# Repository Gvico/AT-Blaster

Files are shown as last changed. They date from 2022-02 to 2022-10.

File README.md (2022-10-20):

# AT-Blaster

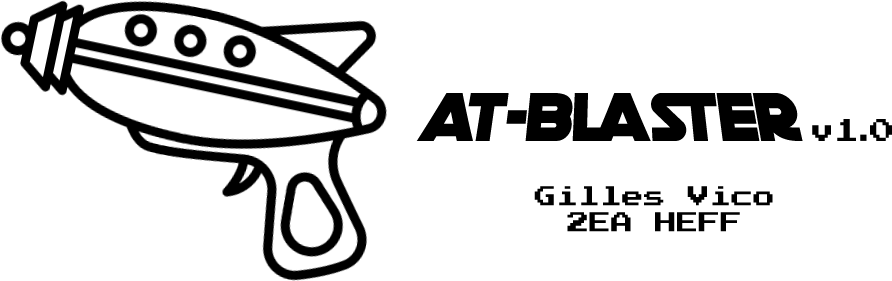
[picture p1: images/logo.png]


AT-Blaster is a BA2 project in Applied Electronics.
Its goal is to recreate a custom lasergame system.

## Project Specs

- **Microcontroller :** ATmega328P U-TH
- **IR Receiver :** VS1838B Module
- **RF Transceiver :** HC-12 Module
- **Display :** 16x2 characters LCD
- **Power :** 9V battery

- **PCB Dimensions :** 50x176mm
- **Case :** Designed on Fusion 360 and 3D printed
- **Components price (as of May 2021, excluding PCB and case) :** 43,51 €

## Features

### SW 1.0 (May 25th 2021)

#### - HW Blaster :

Blaster HW 1.0 support (Semi-automatic pistol)

#### - Free For All mode :

Unlimited lives, 50 points per successful shot.
The first player to reach 1000 points wins the game!

### Room for improvement

#### - Hardware++

Support of new material (manual, automatic variants...)
Blaster HW 2.0 with improved ergonomics and aim system

#### - Modes++

Support for new game modes (teams, protect the king, zombie...)

#### - Connectivity++

Support for a base running on a Raspberry Pi.
Score screen, score card printing, centralized management...

## Images

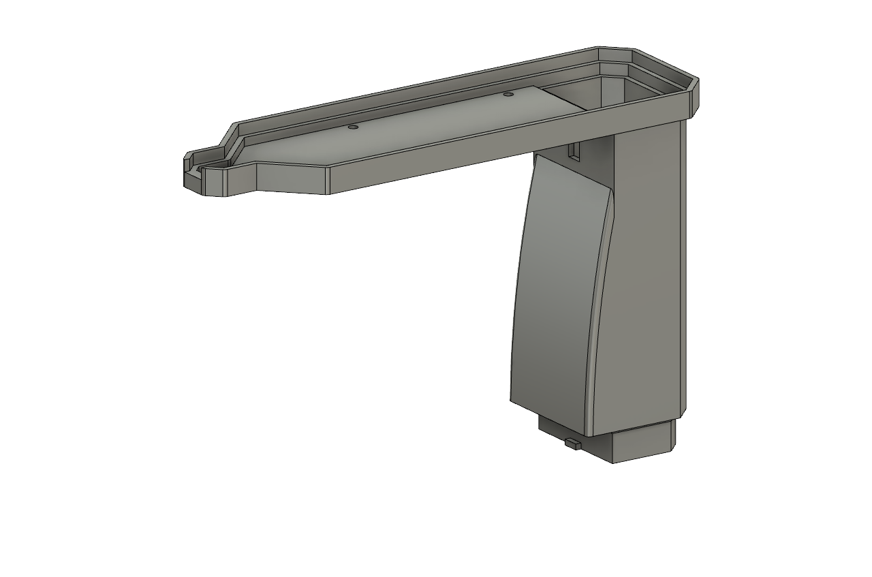
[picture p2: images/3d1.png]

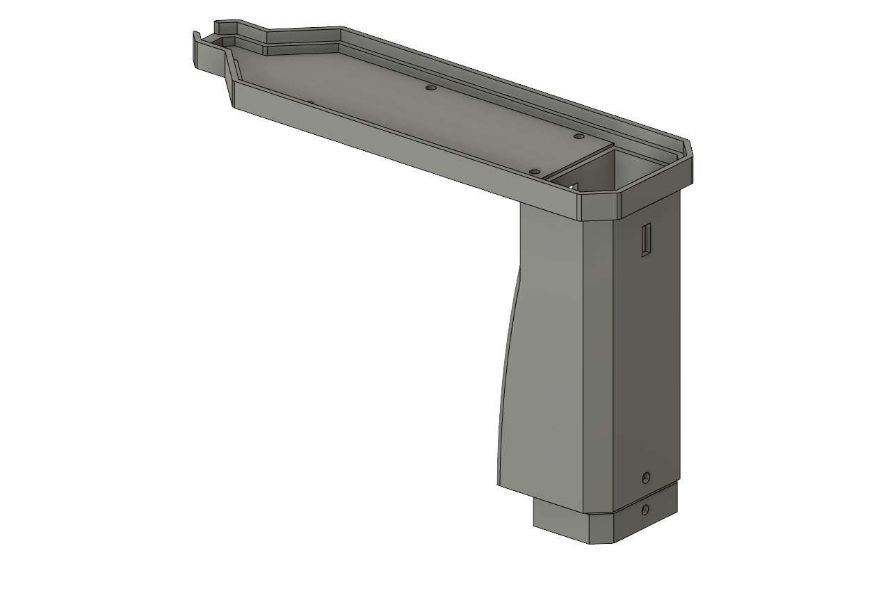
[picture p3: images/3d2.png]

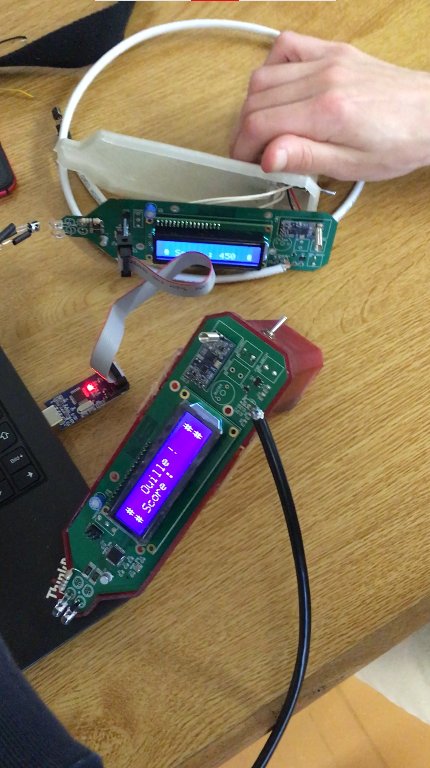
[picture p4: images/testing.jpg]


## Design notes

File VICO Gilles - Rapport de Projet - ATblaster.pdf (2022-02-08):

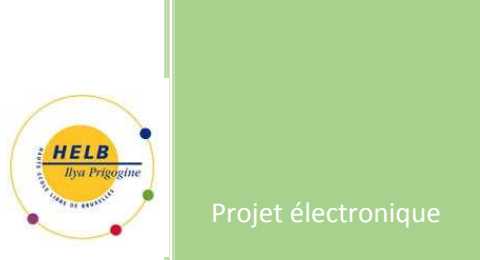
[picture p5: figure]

Département Technique | Projet électronique

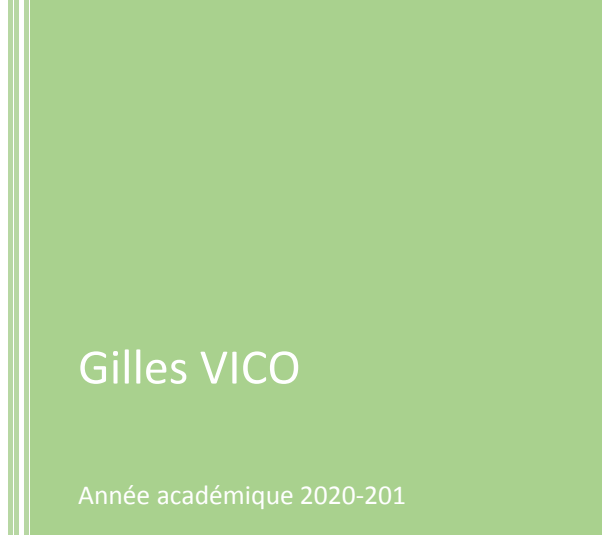
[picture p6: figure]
Gilles VICO; Année académique 2020-201

## Table des matières

# 1. Introduction

M’intéressant au monde du loisir et cherchant de nouvelles façons de m’amuser avec mes amis tout en respectant la distanciation sociale, j’ai décidé de concevoir mon propre système de Laser Game.

Les systèmes existants sur le marché sont généralement chers et ne répondent pas à mes attentes, ce projet me permet donc d’obtenir quelque chose de plus modulable que je pourrai adapter en fonction de mes besoins.

Je pourrais même en faire un jeu de tir sur cibles sans avoir à modifier le hardware.

Chaque joueur possède un pistolet. Les pistolets communiquent leur « tir » via de la lumière infrarouge : des LED au bout du pistolet, et un capteur positionné sur le torse du joueur.

Je me suis fixé l’objectif de pouvoir faire un suivi des scores, de façon à pouvoir déterminer un joueur gagnant à la fin de la partie. Pour ce faire, je me suis servi de modules radio, qui permettront aux pistolets de communiquer entre eux de façon non-directionnelle.

L’objectif de départ était d’avoir un simple système de pistolets, avec une LED servant à indiquer le gagnant en fin de partie.

Des fonctions bonus ont également été envisagées en fonction du temps restant disponible :

- Un écran LCD pour afficher les scores en temps réel
- Un buzzer pour émettre un signal sonore quand le pistoler tire
- Un moteur permettant de faire vibrer le pistolet quand il se fait toucher

# 2. Spécifications techniques

- Microcontrôleur : ATmega328P U-TH
- Transmission infrarouge : LEDs infrarouge
- Réception infrarouge : Module VS1838B
- Transmission et réception radio : Module HC-12
- Affichage : LCD 16x2 caractères
- Alimentation : Pile 9V interchangeable
- Dimensions du PCB : 50*176mm
- Boîtier imprimé en 3D
- Prix des composants d’un pistolet (PCB non-inclus) : 43,51 €

# 3. Schéma bloc

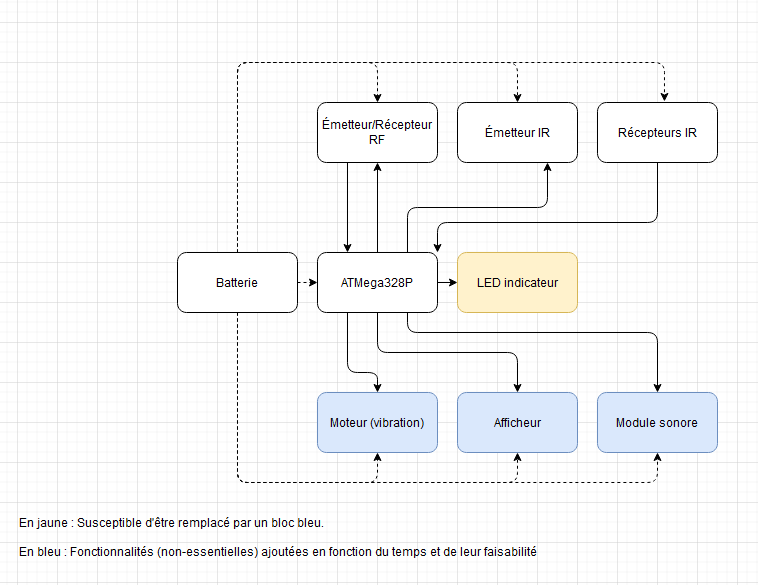
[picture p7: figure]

Le LCD a finalement remplacé la LED indicateur.

Le buzzer et le moteur ont aussi été prévus sur le PCB.

Un régulateur s’assure que la tension Vcc est de 5V.

La transmission IR assure la détection des tirs.

La transmission RF assure la communication entre les pistolets.

# 4. Schéma électronique

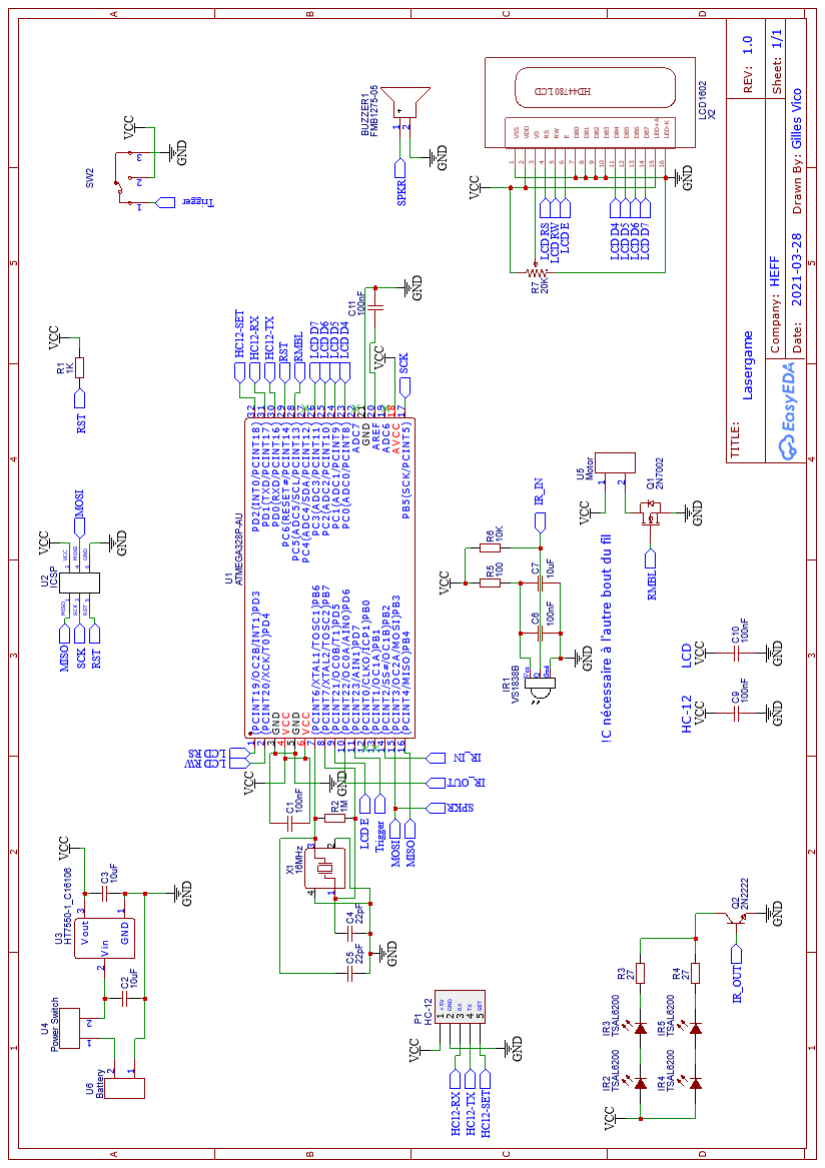
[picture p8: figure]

# 5. Choix de composants

La plupart des composants (dont le microcontrôleur et son cristal) ont été choisis dans leur version CMS, afin de gagner de la place.

Pour l’émission infrarouge, le choix n’est pas bien compliqué et les LEDs infrarouges s’imposent. Un système de laser aurait été techniquement possible, mais en plus de coûter beaucoup plus cher il est dangereux : la lumière du laser occasionne des dégâts aux yeux, sans même qu’on ne puisse s’en rendre compte, celle-ci étant invisible.

Plusieurs LEDs ont été utilisées ici afin de renforcer la puissance de l’émission.

Pour la transmission et réception radio, plusieurs modules ont été considérés :

- Tout d’abord des nrf24l01, mais ceux-ci utilisaient un protocole limitant les possibilités (notamment en ne permettant la communication qu’entre un nombre limité d’appareils), et s’avèrent compliqués à l’utilisation.
- Des modules génériques ont aussi été testés, leur prix les rendait intéressants mais leurs performances étaient particulièrement médiocres, la communication s’interrompant après moins d’un mètre.
- Finalement, les modules retenus sont les HC-12, qui sont performants, ont un prix raisonnable et sont faciles à utiliser. Etant de la même famille que les HC-05 vus en cours de systèmes à microcontrôleurs, il était d’autant plus simple de travailler avec ceux-ci.

Pour l’afficheur, un LCD 16x2 caractères identique à celui utilisé en cours de systèmes à microcontrôleurs a été utilisé, car celui-ci est connu et donc plus simple à utiliser.

La programmation de l’ATmega328P se fait directement via ICSP. Un branchement en USB n’est pas nécessaire, et le bus UART est de toute façon déjà utilisé par le module HC-12.

Un régulateur est présent pour assurer une tension de 5V, d’autres tensions (comme 3.3V) ne sont pas requises.

# 6. Mise en œuvre de la CEM

Voir les images du PCB pour illustration.

Afin de réduire au maximum le bruit électrique dans le circuit, plusieurs précautions ont été prises :

- Un plan de masse est présent sur les deux faces du PCB.
- Des condensateurs de découplage de 100nF sont placés entre Vcc et la masse, au plus proche de chaque composant actif.
- Les pistes ne font jamais d’angle autre que 45°.
- La tension Vcc est distribuée le long d’une piste principale.
- Les fils utilisés pour transporter la tension et le signal du module VS1838B, éloigné du PCB pour être sur le torse du joueur, sont blindés.

# 7. Liste de matériel (BOM)

BOM : AT-Blaster v1.0
1 | ATmega328P U-TH | 3,25 € | 3,25 €
1 | HC-12 | 9,90 € | 9,90 €
1 | LCD 16x2 | 11,03 € | 11,03 €
1 | Micro-switch | 2,70 € | 2,70 €
1 | Switch | 1,32 € | 1,32 €
2 | LED IR | 1,32 € | 2,64 €
1 | VS1838B | 0,44 € | 0,44 €
1 | Header 1x30 | 1,17 € | 1,17 €
1 | Batterie 9V | 7,47 € | 7,47 €
1 | HCT7750 | 0,17 € | 0,17 €
1 | 2N2222 | 0,48 € | 0,48 €
1 | 2N7002 | 0,09 € | 0,09 €
1 | 75H 20K | 1,01 € | 1,01 €
1 | 16MHz Xtal | 1,01 € | 1,01 €
3 | 10µF céramique | 0,10 € | 0,30 €
2 | 22pF céramique | 0,04 € | 0,08 €
5 | 100nF céramique | 0,02 € | 0,10 €
1 | 1K 0805 | 0,02 € | 0,02 €
1 | 1M 0805 | 0,25 € | 0,25 €
2 | 27E 2512 | 0,02 € | 0,04 €
1 | 100E 0805 | 0,02 € | 0,02 €
1 | 10K 0805 | 0,02 € | 0,02 €
Total : | | | 43,51 €

# 8. Conception du PCB

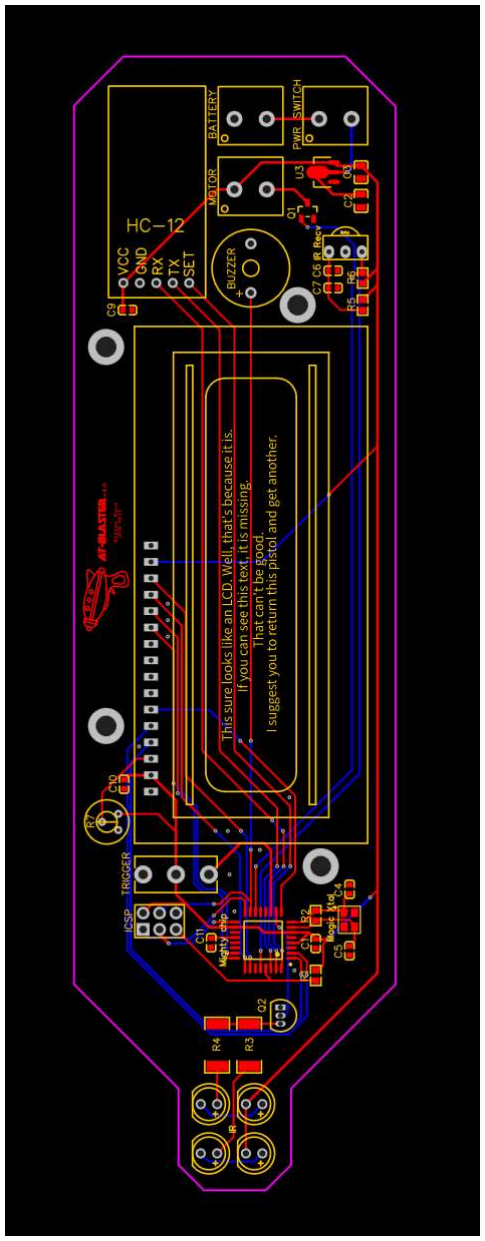
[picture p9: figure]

Dans cette vue, le plan de masse n’est pas activé afin que tout soit visible.

Le PCB a été réalisé avec EasyEDA.

Ce afin d’expérimenter d’autres logiciels de CAO, et de pouvoir profiter du service d’assemblage de JLCPCB, société par laquelle sont commandés les PCB.

Les composants ont été placés en gardant à l’esprit la forme du pistolet : le PCB devait donc être allongé, avec le LCD au centre, la connectique externe majoritairement à l’arrière (de façon à pouvoir faire passer des fils dans la poignée du pistolet), et les LEDs infrarouges à l’avant.

Des trous ont également été prévus afin de pouvoir fixer le PCB au boitier avec des vis.

# 9. Code C

main.c

#include "Drivers/Headers/IO_Config.h" #include "Drivers/Headers/UART_Config.h"

#include "Application/Headers/Globals.h" #include "Application/Headers/Defines.h" #include "Application/Headers/LCD.h" #include "Application/Headers/HC-12.h" #include "Application/Headers/Lasergame.h"

#include <avr/interrupt.h>

#include <avr/io.h>

#include <util/delay.h>

#include <string.h>

#include <stdlib.h>

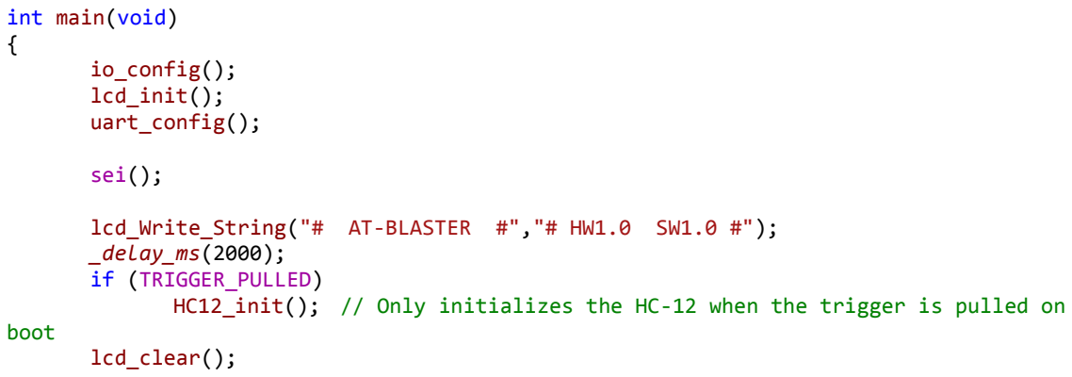
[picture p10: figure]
int main(void) {; io_config(); lcd_init(); uart_config();; sei();; _delay_ms(2000); if (TRIGGER_PULLED); boot; lcd_clear();

lcd_Write_String("# AT-BLASTER #","# HW1.0 SW1.0 #");

HC12_init(); // Only initializes the HC-12 when the trigger is pulled on

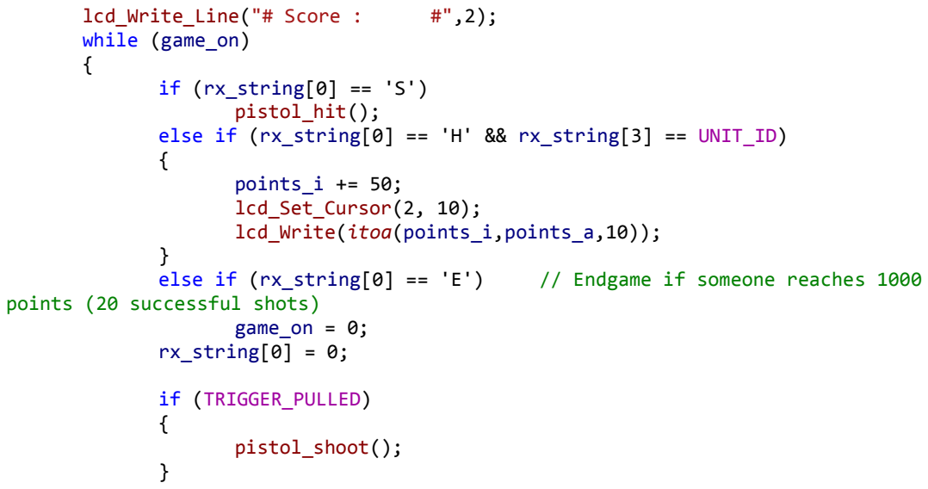
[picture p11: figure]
lcd_Write_Line("# Score :; while (game_on) {; if (rx_string[0] == 'S') pistol_hit();; points_i += 50; lcd_Set_Cursor(2, 10); lcd_Write(itoa(points_i,points_a,10));; points (20 successful shots) game_on = 0; rx_string[0] = 0;; if (TRIGGER_PULLED) {; pistol_shoot();

else if (rx_string[0] == 'H' && rx_string[3] == UNIT_ID)

else if (rx_string[0] == 'E') // Endgame if someone reaches 1000

if (points_i == 1000)
pistol_endgame();
}

while (1)
{
if (points_i == 1000)
lcd_Write_Line("# Victoire ! #", 1); else
lcd_Write_Line("# Game Over #", 1);

_delay_ms(1000);
lcd_Write_Line("# | #", 1);
_delay_ms(500);
}
}

IO_Config.c

#include "../Headers/IO_Config.h" #include <avr/io.h>

void io_config(void)
{
/* IO direction definition - 1 for output*/ DDRB = 0b00001000;
DDRC = 0b00101111;
DDRD = 0b01111110;

/* Input pull-up control - 0 to disable*/
/* Output value control - pull-up always disabled in this case*/ PORTB = 0b00110011;
PORTC = 0b00010000;
PORTD = 0b00000100;

/* Input value */
/* Writing a 1 toggle PORTx value (pull-up ctrl if input or output value)*/ PINB = 0x00;
PINC = 0x00;
PIND = 0x00;

/* Global pull-up control on inputs - 1 to disable*/ MCUCR = 0x00;
}

UART_Config.c

#include <avr/io.h>

void uart_config(void)
{
UCSR0A = 0x00; | //single speed - multiprocessor off
UCSR0B = 0b10011000; | //RX int ON - TX int OFF - RX enable - TX enable
UCSR0C = 0b00000110; | //Asynchronous - No Parity - 8 Data bits - 1 Stop
bit
UBRR0 = 103; | //9600bps
}

void uart_send(char data)
{
while (!(UCSR0A & (1<<UDRE0)));

UDR0 = data;
}

void uart_send_string(char *data) {
while (*data)
uart_send(*data++);
}

Globals.c

#include "../Headers/Globals.h"

volatile char rx_string[8]; volatile char rx_i = 0;

char game_on = 1;
int points_i = 0;
char points_a[5];

Defines.c

#ifndef DEFINES_H_

#define DEFINES_H_

#ifndef F_CPU

#define F_CPU 16000000UL // 16 MHz #endif

#ifndef byte

#define byte unsigned char

#endif

#ifndef uint

#define uint unsigned int

#endif

#ifndef ulong

#define ulong unsigned long

#endif

#ifndef UNIT_ID

#define UNIT_ID 0x02 // Unique ID to identify each pistol #endif

#ifndef IR_ON

#define IR_ON PORTD |= 0b01000000

#endif

#ifndef IR_OFF

#define IR_OFF PORTD &= 0b10111111

#endif

#ifndef INCOMING_IR

#define INCOMING_IR (PINB & (1 << PINB2)) != (1 << PINB2) // PINB2 low when IR input

#endif

#ifndef TRIGGER_PULLED

#define TRIGGER_PULLED (PIND & (1 << PIND7)) == (1 << PIND7) // PIND7 high when trigger pulled

#endif

#endif /* DEFINES_H_ */

LCD.c

#include "../Headers/LCD.h" #include "../Headers/Globals.h" #include "../Headers/Defines.h"

#include <util/delay.h>

/*****************************************************
Function: | lcd_init
Receive : | nothing
Send: | nothing
Description: LCD initialization
!! SHALL BE CALLED ONCE BEFORE USING LCD TO CONFIGURE IT PROPERLY !!
*****************************************************/

void lcd_init(void)
{
RS_CLR;
Data_PORT_CLR;

_delay_ms(5);
Data_PORT |= 0x20 >> 4;
EN_SET;
_delay_ms(5);
EN_CLR;
lcd_cmd(0x28); | // 4-bit mode - 2 line - 5x7 font.
lcd_cmd(0x01); | // Clear display
lcd_cmd(0x0c); | // Display no cursor - no blink.
lcd_cmd(0x06); | // Automatic Increment - No Display shift.
lcd_cmd(0x80); | // Address DDRAM with 0 offset 80h.
}

/*****************************************************
Function: | lcd_cmd
Receive : | command to send to LCD
Send: | nothing
Description: used to send commands to LCD.

SHOULD ONLY BE USED IN LCD.C *****************************************************/

void lcd_cmd(char cmd)
{
RS_CLR;
Data_PORT_CLR;
//Data_PORT |= (cmd & 0xf0); Data_PORT |= (cmd & 0xf0)>>4; EN_SET;
_delay_ms(5);
EN_CLR;
Data_PORT_CLR;
//Data_PORT |= ((cmd<<4) & 0xf0); Data_PORT |= ((cmd<<4) & 0xf0)>>4; EN_SET;
_delay_ms(5);
EN_CLR;
}

/*****************************************************
Function: | lcd_data
Receive : | data to send to LCD
Send: | nothing
Description: used to send data to LCD in 4bits mode

CAN BE USED OUTSIDE LCD.C TO SEND 8bits DATA TO LCD *****************************************************/

void lcd_data(char data)
{
RS_SET;
Data_PORT_CLR;
Data_PORT |= (data & 0xf0)>>4; EN_SET;
_delay_ms(5);
EN_CLR;
Data_PORT_CLR;
Data_PORT |= ((data<<4) & 0xf0)>>4; EN_SET;
_delay_ms(5);
EN_CLR;
}

/*****************************************************
Function: | lcd_clear
Receive : | nothing
Send: | nothing
Description: used to clear LCD screen

CAN BE USED OUTSIDE LCD.C TO CLEAR LCD SCREEN *****************************************************/

void lcd_clear(void)
{
lcd_cmd(0x01); | // Clear display
}

/*****************************************************
Function: | lcd_Set_Cursor
Receive : | a, position on first LCD line
b, position on second LCD line
Send: | nothing
Description: used position cursor on LCD screen

CAN BE USED OUTSIDE LCD.C TO POSITION CURSOR ON SCREEN *****************************************************/

void lcd_Set_Cursor(char a, char b)
{
if(a == 1)lcd_cmd(0x80 + b);
else if(a == 2)lcd_cmd(0xC0 + b);
}

/*****************************************************
Function: | lcd_Write_String
Receive : | a, text on first LCD line
b, text on second LCD line
Send: | nothing
Description: used to write text on LCD screen

USED OUTSIDE LCD.C TO POSITION CURSOR ON SCREEN *****************************************************/

void lcd_Write_String(char *a,char *b)
{
int i;

lcd_clear();

lcd_Set_Cursor(1,0);
for(i=0;a[i]!='\0';i++) lcd_data(a[i]);

lcd_Set_Cursor(2,0);
for(i=0;b[i]!='\0';i++) lcd_data(b[i]);
}

/*****************************************************
Function: | lcd_Write_Line
Receive : | s, text on LCD line
b, LCD line select
Send: | nothing
Description: used to write text on one line of the LCD screen without clearing it *****************************************************/

void lcd_Write_Line(char *s,char l)
{
int i;

lcd_Set_Cursor(l,0);
for(i=0;s[i]!='\0';i++) lcd_data(s[i]);
}

/*****************************************************
Function: | lcd_Write
Receive : | s, text on LCD line
Send: | nothing
Description: used to write text when cursor position is already defined *****************************************************/

void lcd_Write(char *s)
{
int i;
for(i=0;s[i]!='\0';i++) lcd_data(s[i]); }

HC-12.c

#include "../Headers/Defines.h"

#include "../../Drivers/Headers/UART_Config.h"

#include <avr/io.h>

#include <util/delay.h>

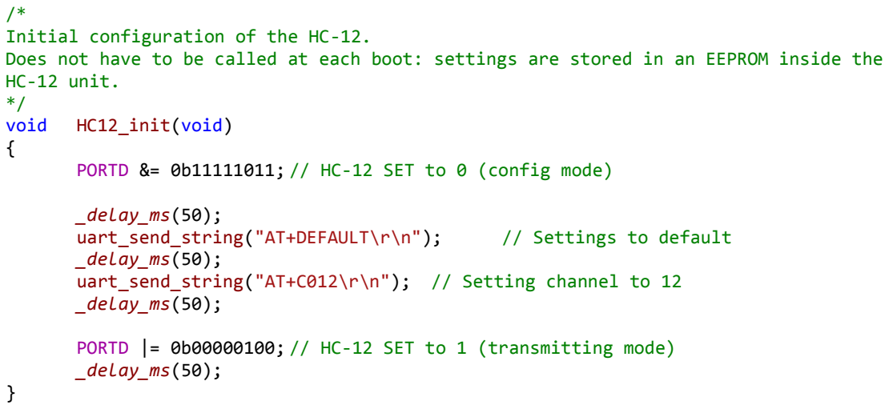
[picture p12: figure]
/* Initial configuration of the HC-12.; HC-12 unit. */; void; HC12_init(void); _delay_ms(50);

Does not have to be called at each boot: settings are stored in an EEPROM inside the

PORTD &= 0b11111011; // HC-12 SET to 0 (config mode)

uart_send_string("AT+DEFAULT\r\n"); | // Settings to default

uart_send_string("AT+C012\r\n"); // Setting channel to 12

PORTD |= 0b00000100; // HC-12 SET to 1 (transmitting mode)

Lasergame.c

#include "../Headers/Defines.h"

#include "../Headers/Globals.h"

#include "../Headers/LCD.h"

#include "../../Drivers/Headers/UART_Config.h"

#include <util/delay.h>

/*
RF data memento:
x being the ID of the unit
y being the ID of another unit
- Sx : "I am shooting"
- Hx : "I am hit"
- By : "I was shot by y"
- Ey : Endgame, y won
- # : Terminating character */

void pistol_hit(void)
{
if (INCOMING_IR)
{
_delay_ms(5);
if (INCOMING_IR) // IR signal must be maintained for 5ms to avoid false detections due to ambient light {
lcd_Write_Line("# | Ouille ! | #",1);

uart_send('H');
uart_send(UNIT_ID);
uart_send('B');
uart_send(rx_string[1]); // The ID of the other unit uart_send('#');
_delay_ms(2000); | // 2 seconds of immunity when hit
lcd_Write_Line("# | | #",1);
}
}
}

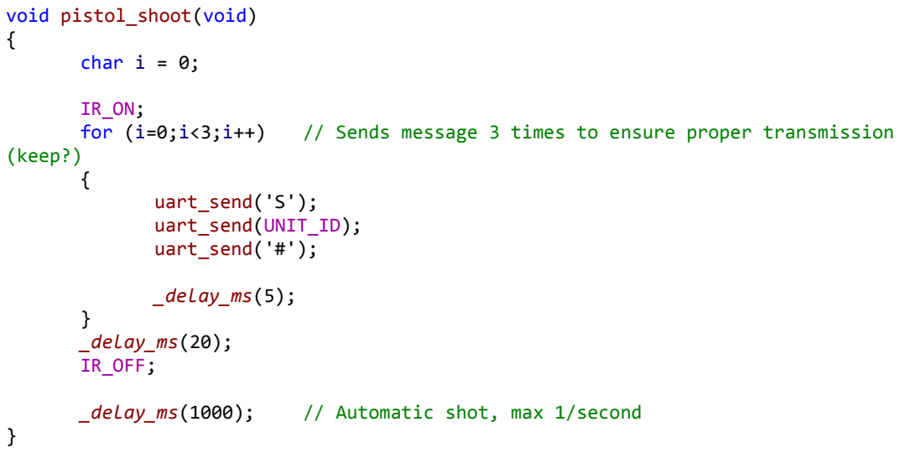
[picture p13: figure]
void pistol_shoot(void) {; char i = 0;; (keep?) {; uart_send('S'); uart_send(UNIT_ID); uart_send('#');; _delay_ms(5);; } _delay_ms(20); IR_OFF;

for (i=0;i<3;i++) | // Sends message 3 times to ensure proper transmission
_delay_ms(1000); | // Automatic shot, max 1/second

void pistol_endgame(void)
{
uart_send('E');
uart_send(UNIT_ID);
uart_send('#');
game_on = 0;
}

Int_Vectors.c

#include "../Headers/Globals.h"

#include "../Headers/Defines.h"

#include "../../Drivers/Headers/UART_Config.h"

#include <avr/interrupt.h>

#include <avr/io.h>

ISR(USART_RX_vect)
{
rx_string[rx_i] = UDR0;

if (rx_string[rx_i] == '#')// RF commands must end with '#' rx_i = 0;
else
rx_i++;
}

# 10.Explication du fonctionnement

Au démarrage, si nécessaire, le module HC-12 est configuré. Une configuration systématique n’est pas nécessaire, le module disposant d’une EEPROM pour sauvegarder les paramètres.

Les autres configurations sont ensuite faites.

Pendant le jeu, le programme vérifie en continu au cas où un message serait reçu par radio, ou si la gâchette est tirée.

Si la gâchette est tirée :

- Les LEDs infrarouge s’allument.
- Le programme envoie un message radio indiquant que le pistolet est en train de tirer.

Si un message est reçu, plusieurs choses peuvent arriver en fonction du message :

- Si quelqu’un tire, le programme vérifie si un signal infrarouge est reçu en même temps. Si c’est le cas et qu’il est maintenu pendant 5ms (pour éviter les faux positifs), c’est que le joueur se fait tirer dessus. Le programme l’affiche donc, et envoie un message indiquant qu’il s’est fait tirer dessus et relayant son numéro d’identification ainsi que celui du tireur.
- Si quelqu’un s’est fait toucher par le pistolet, le joueur gagne 50 points. Si le joueur totalise 1000 points, il gagne. Le programme communique l’information aux autres unités : le jeu s’arrête.
- Si un autre joueur a gagné la partie, le jeu s’arrête.

A la fin de la partie, l’écran du pistolet gagnant indique « Victoire ! », alors que celui des autres indique « Game Over ».

# 11.Dépannage hardware

Les PCB fabriqués ont deux principaux défauts :

- Il manque une résistance de 470 Ohms entre Vcc et l’alimentation du rétro-éclairage du LCD. Sans cela, il fonctionne quand-même mais consomme beaucoup d’énergie et voit sa durée de vie réduite. La piste d’alimentation a donc été coupée sur chaque pistolet et des résistances SMD de 470 Ohms ont été rajoutées.
- Les LEDs infrarouge consomment trop de courant. Comme il s’agit de deux jeux de deux LEDs en série, le problème peut être résolu en en retirant un de ces deux jeux, et en ajustant la valeur de la résistance limitant le courant qui traverse les LEDs.

Par souci de temps et de ressources, le buzzer et le moteur n’ont pas pu être implémentés.

Par conséquent il est difficile de savoir si leur implémentation hardware possède des défauts. Néanmoins, aucune anomalie n’a été relevée au cours des inspections du PCB.

# 12.Dépannage software

Les avaries du software sont trop nombreuses pour être citées, et même retenues, mais plusieurs aspects du programme ont dû être revus au cours du développement.

Il était notamment prévu au départ que le tireur communique son numéro d’identification via infrarouge, mais il s’est finalement avéré plus simple de communiquer uniquement par radio et d’utiliser l’infrarouge comme un simple indicateur.

La gestion de l’interrupt sur RX a dû être revue plusieurs fois aussi, car elle provoquait dans certains cas un ralentissement significatif du fonctionnement du programme, rendant le pistolet inutilisable. La forme utilisée dans le programme actuel est finalement la plus optimisée parmi celles qui ont été tentées, l’expérimentation a donc été plutôt bénéfique.

# 13. Dessin du boîtier

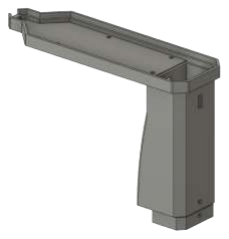
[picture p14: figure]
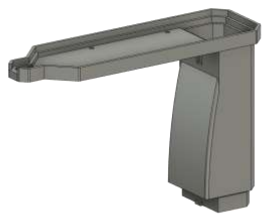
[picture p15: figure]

Le boîtier dispose de trous pour visser le PCB, et la poignée en dispose pour placer l’interrupteur servant à l’alimentation et le micro-switch servant de gâchette.

Le bas de la poignée est amovible afin de pouvoir insérer et changer la batterie.

# 14. Conclusion

Je suis plutôt content de ce que j’ai pu produire, je m’attendais à avoir plus de problèmes que je n’en ai eu réellement et le résultat est assez bon.

Je prévois d’améliorer encore à l’avenir mes pistolets, en diversifiant les modes de jeu ou en centralisant les résultats à l’aide par exemple d’un Raspberry Pi. Je pourrais également réaliser les fonctions bonus que je n’avais pas pu faire cette fois-ci, à savoir le buzzer et le moteur.

Une révision du hardware ne serait même pas forcément nécessaire dans l’immédiat, les problèmes de cette première version étant assez faciles à corriger. Les PCBs que je n’ai pas monté pourront donc me servir.

# 15. Datasheets

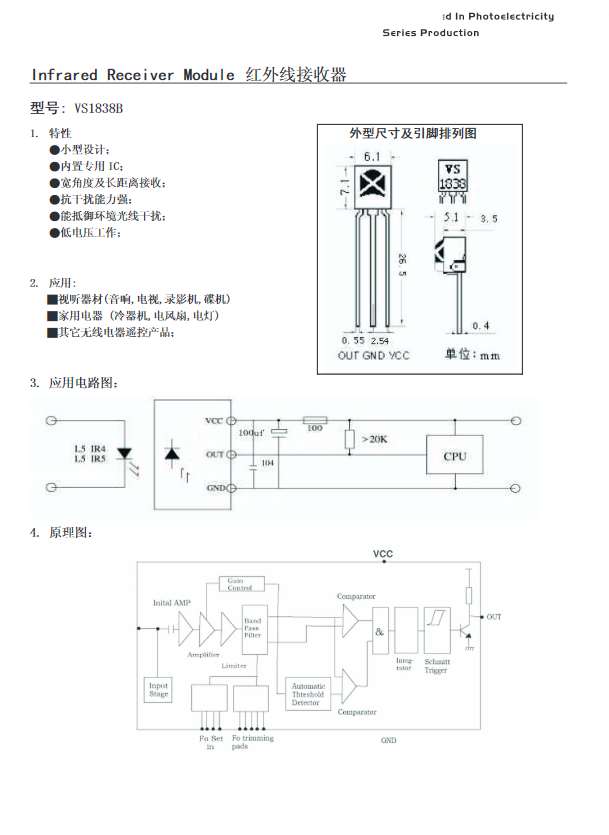
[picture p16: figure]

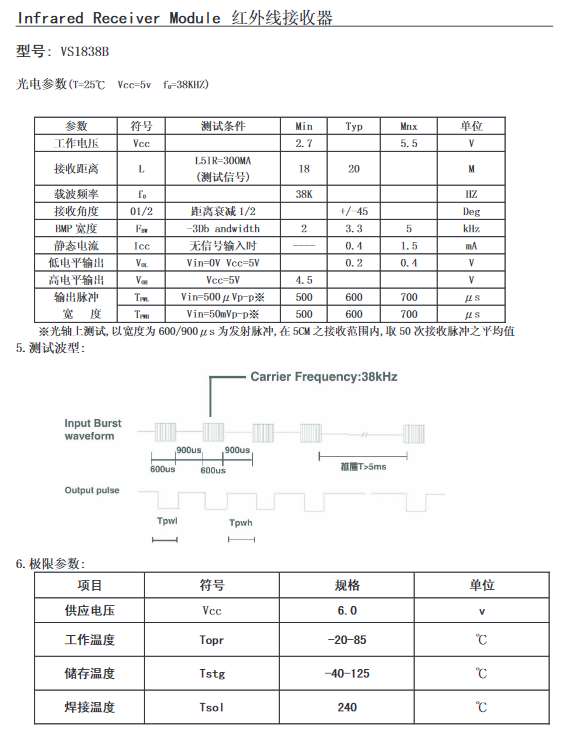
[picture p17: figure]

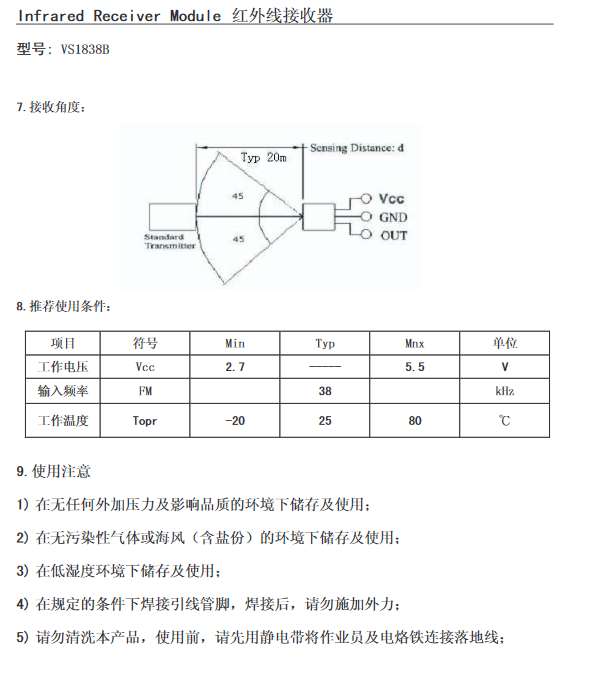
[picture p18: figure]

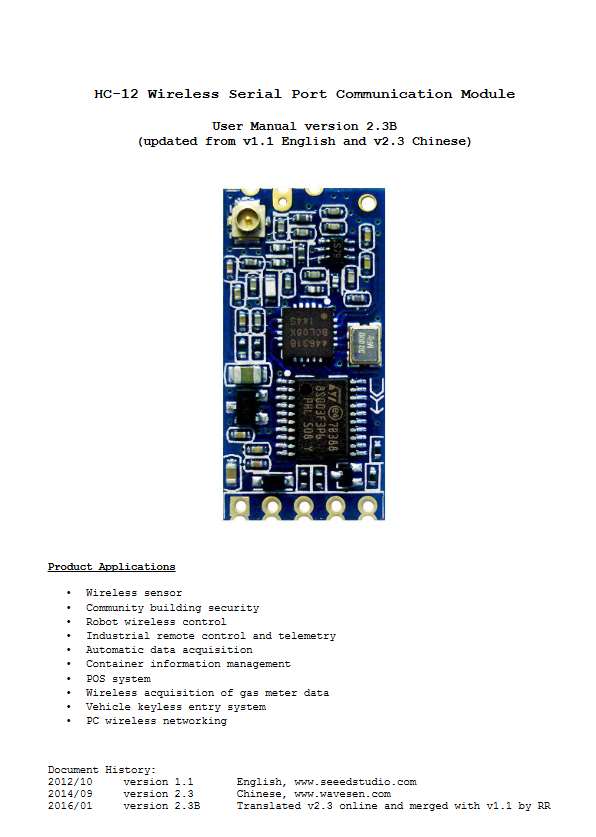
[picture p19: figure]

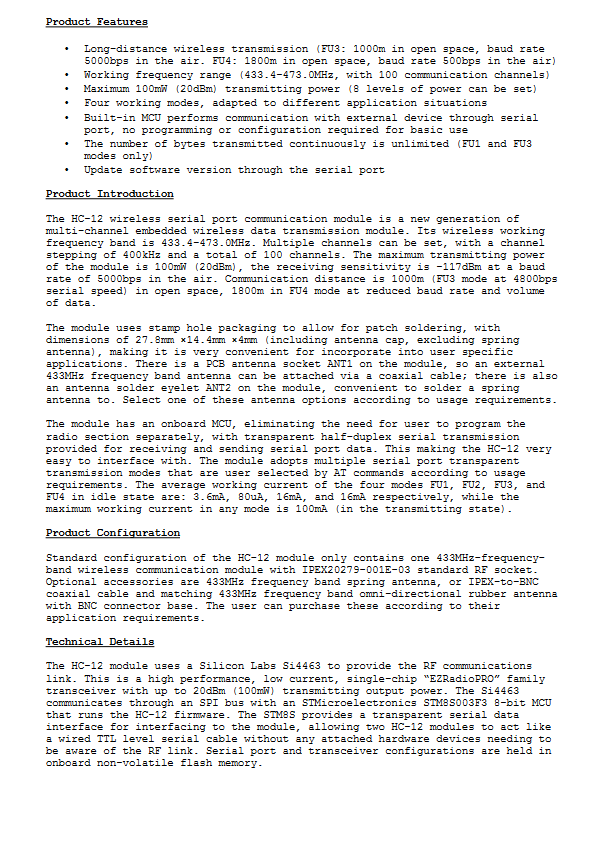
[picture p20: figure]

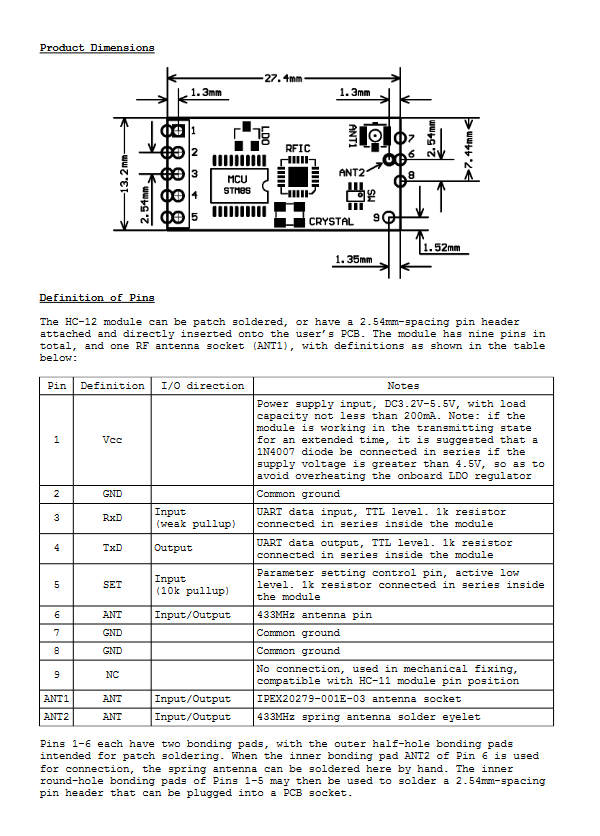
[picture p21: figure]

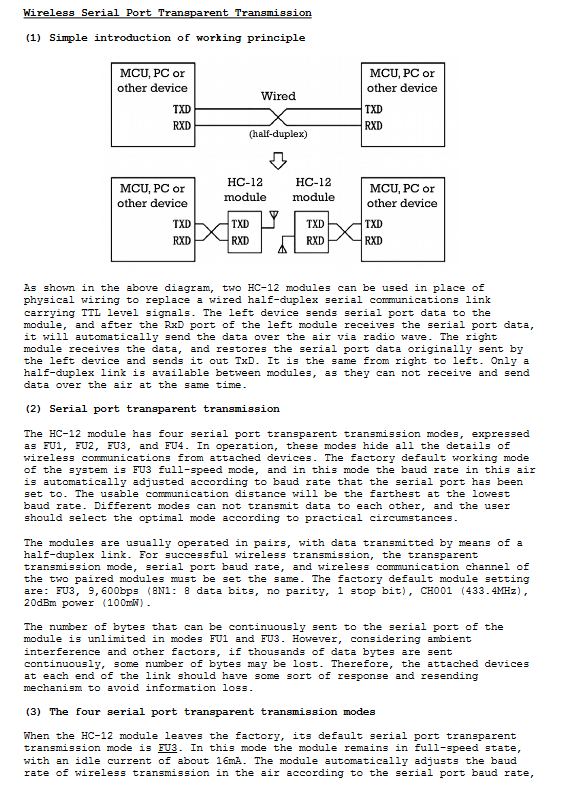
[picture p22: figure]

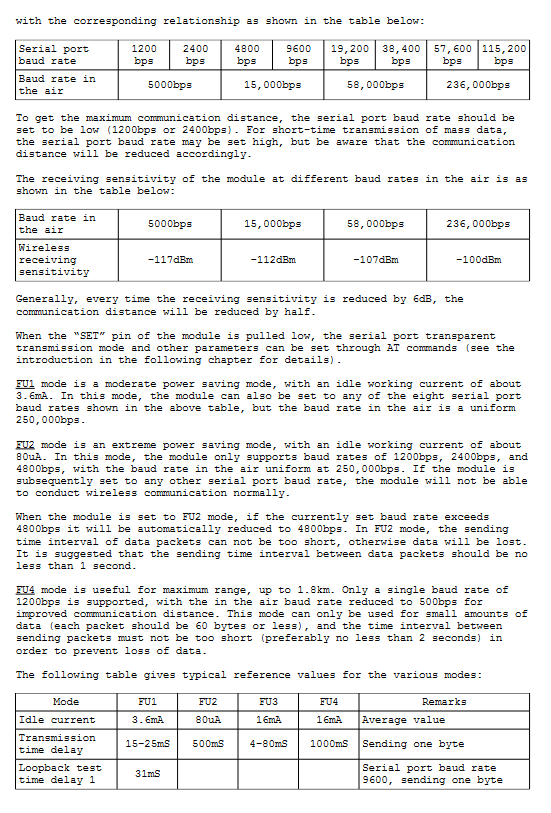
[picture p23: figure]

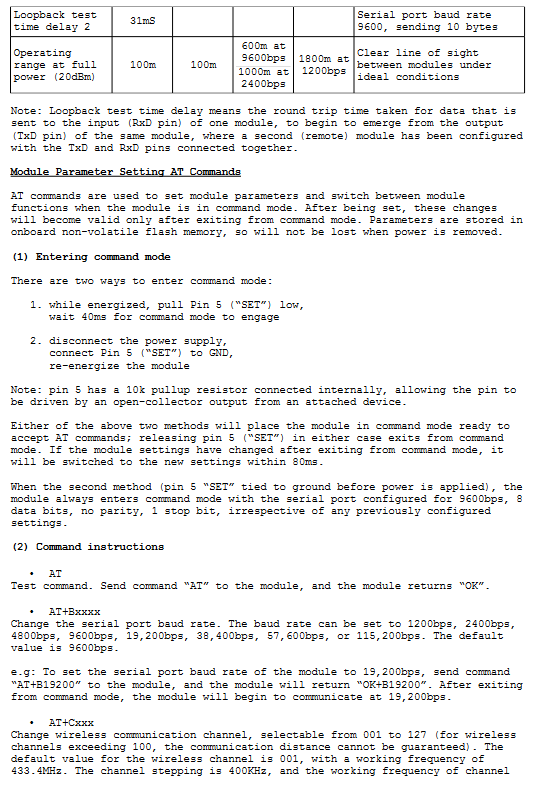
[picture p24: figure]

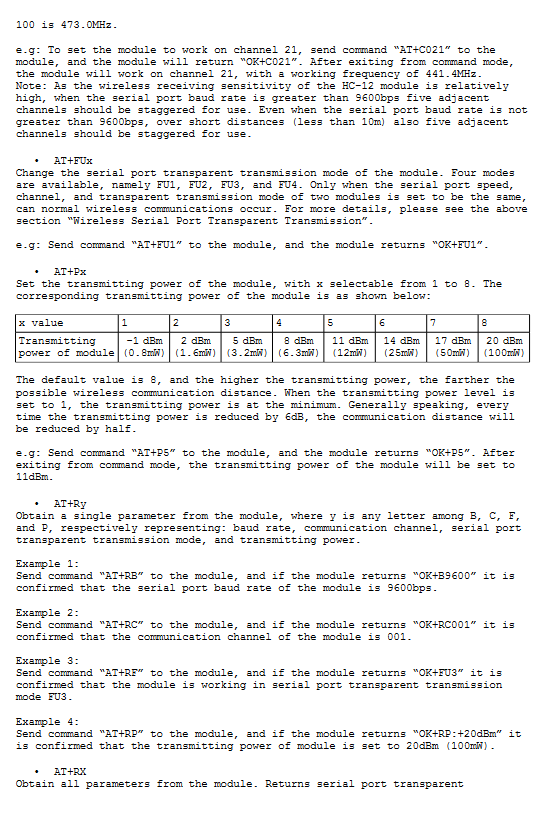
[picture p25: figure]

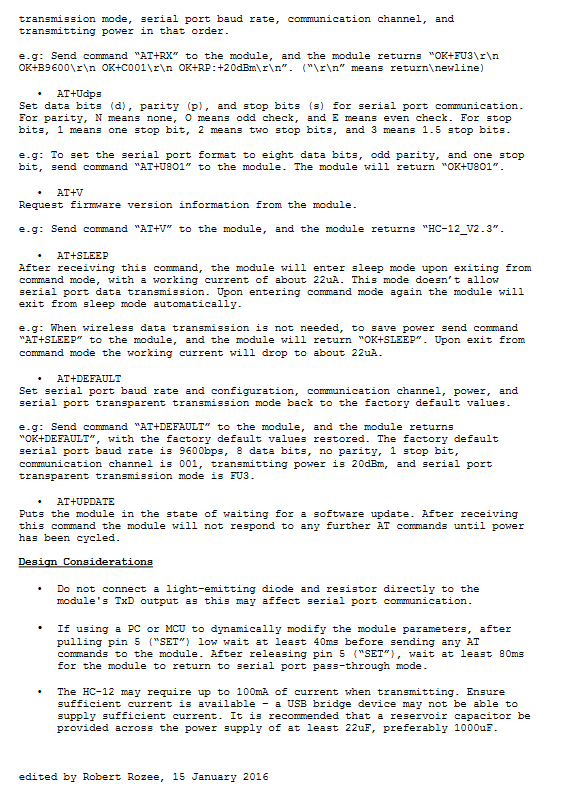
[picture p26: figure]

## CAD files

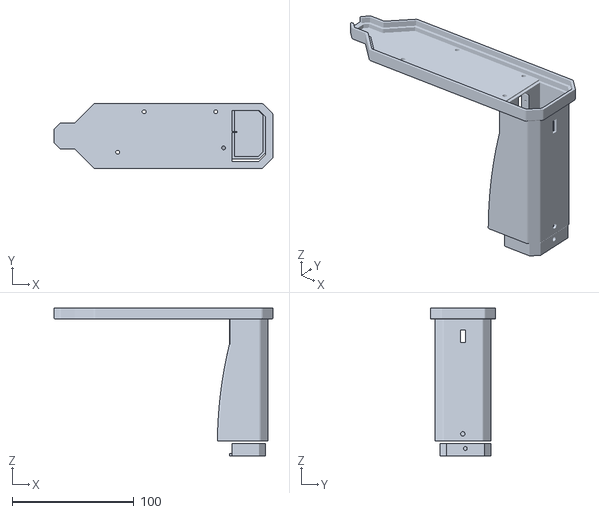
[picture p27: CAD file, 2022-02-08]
3D Files/AT-Blaster 1.0.stl
179.5 x 53.7 x 121.0

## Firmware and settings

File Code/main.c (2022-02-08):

#include "Drivers/Headers/IO_Config.h"
//#include "Drivers/Headers/ExtInt_Config.h"
#include "Drivers/Headers/UART_Config.h"
//#include "Drivers/Headers/Timer_Config.h"

#include "Application/Headers/Globals.h"
#include "Application/Headers/Defines.h"
#include "Application/Headers/LCD.h"
#include "Application/Headers/HC-12.h"
#include "Application/Headers/Lasergame.h"

#include <avr/interrupt.h>
#include <avr/io.h>
#include <util/delay.h>
#include <string.h>
#include <stdlib.h>

/*****************************************************
Function:		main
Receive :		nothing 
Send:			nothing
Description:	Main program function

PROGRAM ALWAYS STARTS BY THIS FUNCTION
*****************************************************/

int main(void)
{
	io_config();
	lcd_init();
	uart_config();
	
	sei();
	
	lcd_Write_String("#  AT-BLASTER  #","# HW1.0  SW1.0 #");
	_delay_ms(2000);
	if (TRIGGER_PULLED)
		HC12_init();	// Only initializes the HC-12 when the trigger is pulled on boot
	lcd_clear();

	lcd_Write_Line("# Score :      #",2);
	while (game_on)
	{
		if (rx_string[0] == 'S')
			pistol_hit();
		else if (rx_string[0] == 'H' && rx_string[3] == UNIT_ID)
		{
			points_i += 50;
			lcd_Set_Cursor(2, 10);
			lcd_Write(itoa(points_i,points_a,10));
		}
		else if (rx_string[0] == 'E')	// Endgame if someone reaches 1000 points (20 successful shots)
			game_on = 0;
		rx_string[0] = 0;
		
		if (TRIGGER_PULLED)
		{
			pistol_shoot();
		}
		
		if (points_i == 1000)
			pistol_endgame();
	}
	
	while (1)
	{
		if (points_i == 1000)
			lcd_Write_Line("#  Victoire !  #", 1);
		else
			lcd_Write_Line("#  Game Over   #", 1);

		_delay_ms(1000);
		lcd_Write_Line("#              #", 1);
		_delay_ms(500);
	}
}

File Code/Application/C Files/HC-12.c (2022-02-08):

/*
 * HC_12.c
 *
 * Created: 03-05-21 08:27:29
 *  Author: Gilles
 */ 

#include "../Headers/Defines.h"
#include "../../Drivers/Headers/UART_Config.h"

#include <avr/io.h>
#include <util/delay.h>

/*
Initial configuration of the HC-12.
Does not have to be called at each boot: settings are stored in an EEPROM inside the HC-12 unit.
*/
void	HC12_init(void)
{
	PORTD &= 0b11111011;	// HC-12 SET to 0 (config mode)
	
	_delay_ms(50);
	uart_send_string("AT+DEFAULT\r\n");	// Settings to default
	_delay_ms(50);
	uart_send_string("AT+C012\r\n");	// Setting channel to 12
	_delay_ms(50);
	
	PORTD |= 0b00000100;	// HC-12 SET to 1 (transmitting mode)
	_delay_ms(50);
}
